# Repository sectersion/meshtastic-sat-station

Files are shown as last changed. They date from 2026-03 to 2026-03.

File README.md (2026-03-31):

# Meshtastic Satellite Weather Station
### A Hack Club Stasis Project

A self-contained, fully off-grid deployable kit that receives real-time weather data directly from GOES satellites and serves it on demand to any nearby Meshtastic mesh node — no internet, no cell service, no infrastructure required.

> Built for [Hack Club Stasis](https://stasis.hackclub.com)
NOTE TO REVIEWERS: The BOM present in my project was exported from google sheets and the links got deleted. The original google sheet is availible in the stasis project itself, and in the README.
---

## The Problem

Weather stations are common on urban LoRa meshes, but they rely on local sensors or internet-connected APIs. In a natural disaster, exactly when weather data matters most, power and internet go down first. A mesh node that can only tell you the temperature outside your window isn't very useful when a tornado is 40 miles away.

## The Solution

This kit receives structured meteorological data broadcasts directly from NOAA's GOES-East geostationary satellite using a software defined radio and a 3D printed helical antenna. It stores a rolling 7-day database of weather data and exposes a query bot on the Meshtastic mesh. Anyone within radio range can request a weather report with a simple command, no app, no internet, no setup on their end.

The entire system runs on solar power and a 3-cell 18650 battery pack, capable of operating for multiple days without sunlight.

---

## Query Interface

Any Meshtastic user within range can query the bot using plain text commands:

```
!wx 30.26 -97.74          → current conditions at coordinates
!wx 30.26 -97.74 3        → 3-day forecast
!fc AUS                   → forecast by airport/station ID
!warn TX                  → active NWS warnings for a state
!help                     → list available commands
```

Responses are formatted to stay under 200 characters, well within LoRa packet limits.

---

## System Architecture

```
GOES-East Satellite (1692.7 MHz EMWIN broadcast)
        |
3D Printed Helical Antenna (RHCP, tuned 1692.7 MHz)
        │
Nooelec SAWbird+ GOES LNA (powered via RTL-SDR bias tee)
        │
RTL-SDR Blog V3 (USB SDR dongle)
        │ USB
Raspberry Pi Zero 2W
 > goestools EMWIN decoder
 > SQLite database (7-day rolling store)
 > Meshtastic bot daemon (Python)
        │ USB serial
RAKWireless RAK4631 + RAK19007
        │ 915 MHz LoRa
Meshtastic mesh network
```

---

## Hardware

### Satellite Receive Chain
The GOES EMWIN signal at 1692.7 MHz broadcasts structured NWS text products: forecasts, warnings, METARs, and observations, in an unencrypted digital format receivable with commodity SDR hardware. The key components are:

- **3D Printed Helical Antenna** — custom designed in Fusion 360, printed on an Elegoo Centauri Carbon, wound with 18 AWG solid copper wire. Axial-mode helix provides natural right-hand circular polarization (RHCP) matching the satellite downlink. Aimed at GOES-East (~35° elevation, due south from Texas).
- **Nooelec SAWbird+ GOES LNA** — inline low-noise amplifier with SAW filter centered at 1688 MHz, providing >20 dB gain. Powered directly from the RTL-SDR V3 bias tee — no separate power required.
- **RTL-SDR Blog V3** — the industry standard hobbyist SDR dongle. Tunes up to ~1.7 GHz with excellent sensitivity.

### Mesh Radio
- **RAKWireless RAK4631** (nRF52840) + **RAK19007 base board** — low power Meshtastic node running stock Meshtastic firmware. Communicates with the Pi over USB serial using the Meshtastic Python library. The nRF52840 chipset draws significantly less power than ESP32-based alternatives, extending battery life.
- **Generic 915 MHz 5.8 dBi fiberglass antenna** — panel mounted to the exterior of the case with the included hardware mount. Omnidirectional, suitable for multi-day high-density mesh operation.

### Computing & Power
- **Raspberry Pi Zero 2W** — runs Raspberry Pi OS Lite, goestools, SQLite, and the bot daemon. Draws ~1.5W under load.
- **TP4056 charge controller** — manages charging of the 3-cell 18650 pack from the solar panels.
- **3x 18650 Li-Ion cells** (~10Ah) — provides ~48 hours of runtime without solar input.
- **2x ALLPOWERS 2.5W 5V solar panels** — wired in parallel, magnetically mounted to the case lid for deployment. Provides realistic 2-3W in partial sun, enough to sustain the system indefinitely in typical conditions.

### The Case
An IP67-rated 11×8×5" hard case serves as the foundation for the entire kit. Interior layout:

- **Left half** — 3D printed brain enclosure housing all electronics, with a magnetic front plate featuring an SSD1306 OLED display and 4 toggle switches
- **Right half** — 3D printed storage trays for the antenna, cables, and mast sections

External hardware includes SMA bulkheads, a cable gland for the solar panel, and the antenna mount — everything needed to go from closed case to fully deployed in under 2 minutes.

### Front Plate Controls
| Switch | Function |
|---|---|
| 1 | System power on/off |
| 2 | Mesh TX enable/disable |
| 3 | Display mode (system status / last query) |
| 4 | Force EMWIN data refresh |

The OLED display shows a split view: system status (satellite lock, battery, node count) on the top half, and the last mesh query and response on the bottom half.

---

## Software Stack

| Component | Technology |
|---|---|
| EMWIN decoder | goestools |
| Database | SQLite (7-day rolling window) |
| Bot daemon | Python, Meshtastic library |
| Display driver | Python, luma.oled |
| Auto-start | systemd services with watchdog |

---

## Deployment

1. Open case, prop lid open
2. Peel solar panels off lid interior stow frame, stick to exterior lid mount
3. Point helical antenna south (~175° azimuth, ~35° elevation) toward GOES-East
4. Flip power switch
5. Within ~60 seconds the Meshtastic node appears on the mesh and the bot is live

---

## BOM

Full bill of materials with pricing and links:
[Google Sheets BOM](https://docs.google.com/spreadsheets/d/1USlBK-dkPbo43bPHNxUITIbZjwFQk0WdP9H-Rfz2vz8/edit?usp=sharing)

**Approximate total: ~$294**

---

## Project Status

- [x] System architecture designed
- [x] BOM finalized
- [x] Front plate modeled in Fusion 360
- [ ] Parts on order
- [ ] EMWIN receive pipeline (goestools + SQLite)
- [ ] Meshtastic bot daemon
- [x] Brain enclosure modeled
- [ ] Helical antenna former modeled and wound
- [ ] Assembly
- [ ] Field test

---

## License

MIT

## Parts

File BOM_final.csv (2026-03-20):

Qty | Name | Purpose | PN | Cost | Link | Total: | 287
1 | RPI 02W | brain | 02W | 30 | link
1 | RTL-SDR Blog V3 R860 | SDR dongle | NA | 40 | link
1 | Nooelec SAWbird+ GOES | LNA | NA | 40 | link
1 | Tp4056 | Charge controller | TP4056 | 6 | link
1 | 18650 3 cell holder | cell holder | NA | 6 | link
1 | 4 pack 3.7v 18650 cell (1 spare) | battery | 18650 | 16 | link
1 | 32GB microSD card | for pi | NA | 9 | link
1 | knockoff pelican case - 11 x 8 x 5 in | enclosure | NA | 26 | link
1 | SMA bulkhead connectors 2 pack | front panel and box | NA | 7 | link
1 | nRF52 meshtastic node | MTS | RAK4631 | 18 | link
1 | meshtastic base board | MTS | RAK19007 | 10 | link
1 | cable gland kit | cheapest one I could find | NA | 8 | link
1 | 3x10mm magnets | cheaper than amazon | NA | 5 | aliexpess
1 | RG316 sma to sma cables 3 pack | <-- | NA | 7 | link
1 | cheap amazon antenna | main 915mhz whip | NA | 18 | link
1 | dust covers sma | <-- | NA | 2 | link
1 | ALLPOWERS solar panel 2x2.5w | auxillary power | NA | 18 | link
1 | 6pcs usbc power pigtail | to connect to tp4056 | NA | 7 | link
1 | 22awg wire | power and other stuff | NA | 8 | link
1 | OLED 0.96in | HUD | NA | 6 | link

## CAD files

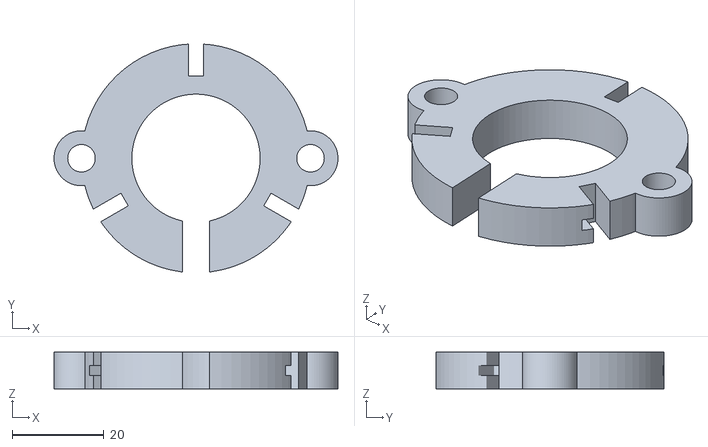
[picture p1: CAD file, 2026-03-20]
models/l-band-helix-bottom-disc-spacer-full-slot.stl
62.0 x 49.7 x 8.00

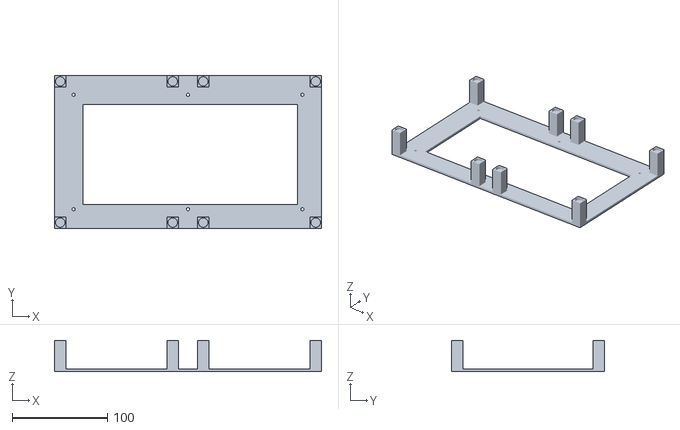
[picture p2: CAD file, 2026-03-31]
models/solar_deploy_mount.stl
280.0 x 160.0 x 33.0

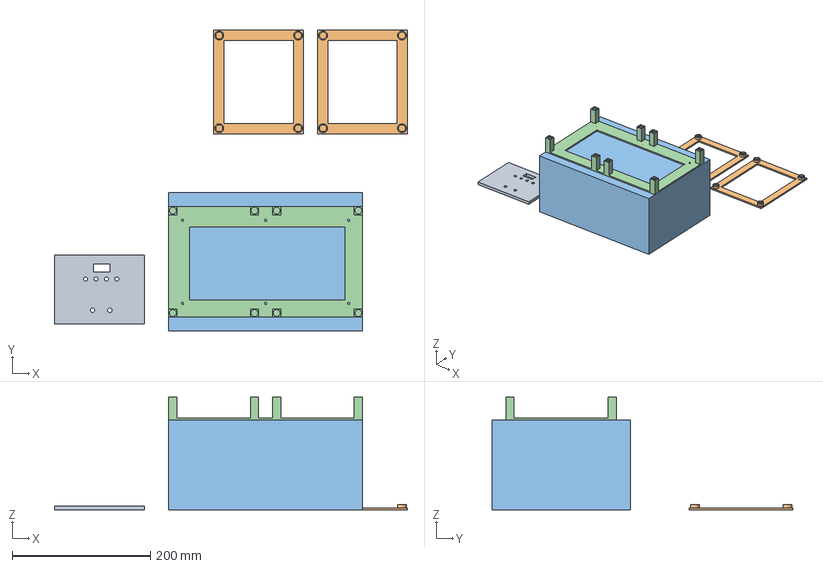
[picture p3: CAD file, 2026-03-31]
panelmount.step
510.0 x 435.0 x 163.0 mm

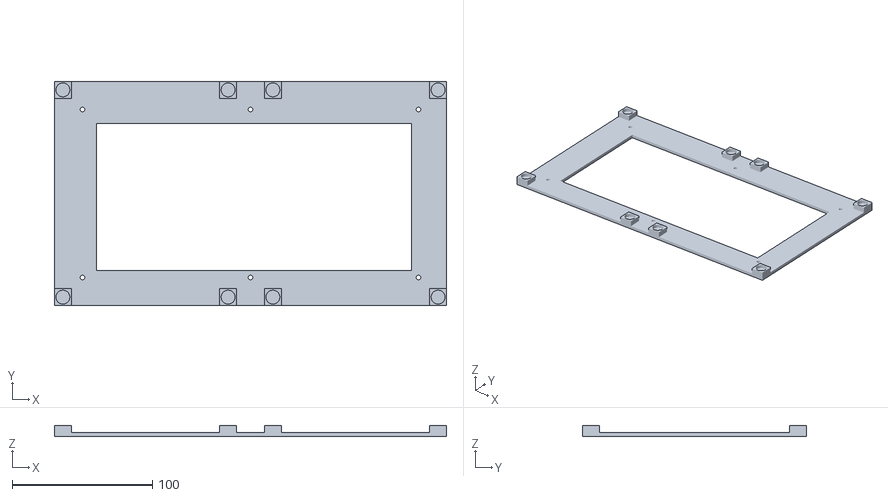
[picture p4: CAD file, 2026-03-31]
models/solar_stow_mount.stl
280.0 x 160.0 x 8.00

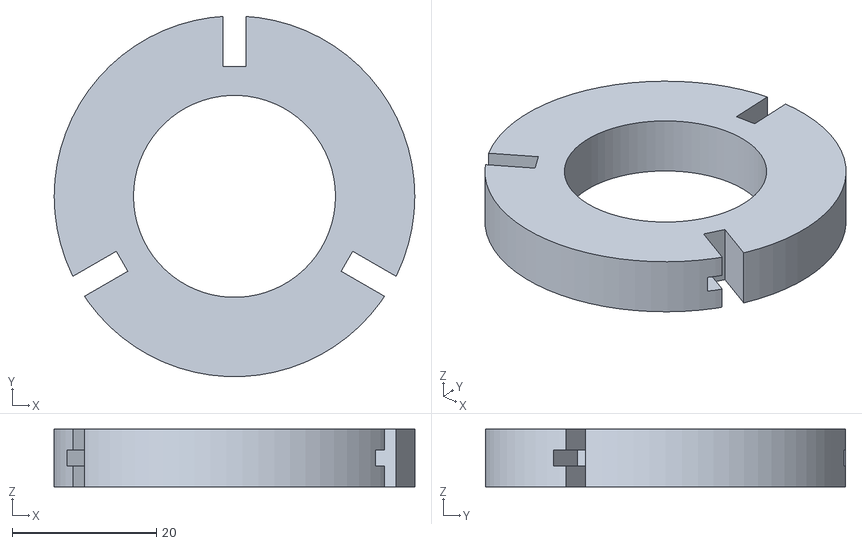
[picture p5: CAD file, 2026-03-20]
models/l-band-helix-upper-disc-spacer.stl
50.0 x 49.9 x 8.00

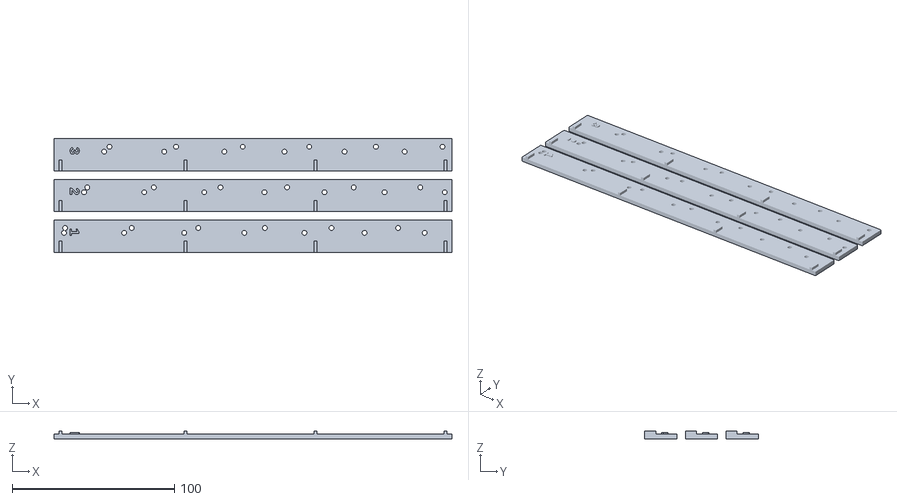
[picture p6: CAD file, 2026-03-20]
models/l-band-helix-vertical-struts.stl
245.0 x 70.0 x 4.90

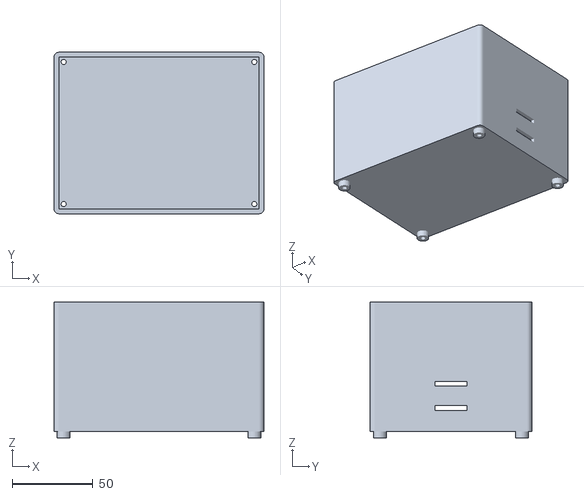
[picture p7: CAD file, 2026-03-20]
models/brain_box.stl
130.0 x 100.0 x 84.0

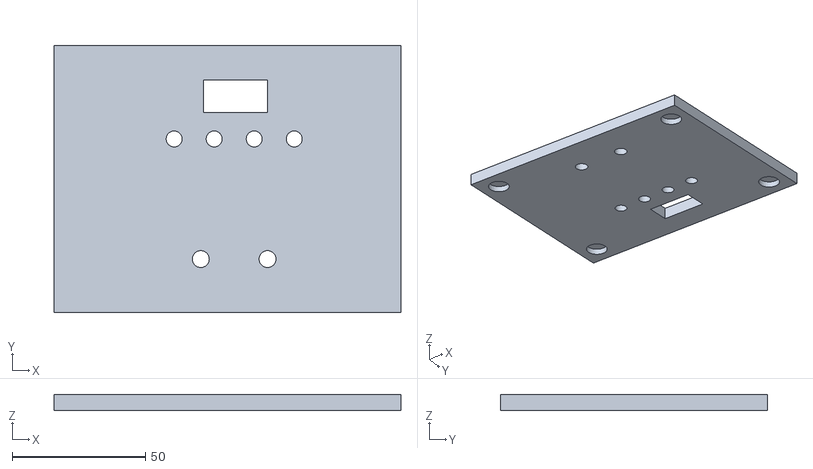
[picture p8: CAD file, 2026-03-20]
models/front_magnet_plate.stl
130.0 x 100.0 x 6.00

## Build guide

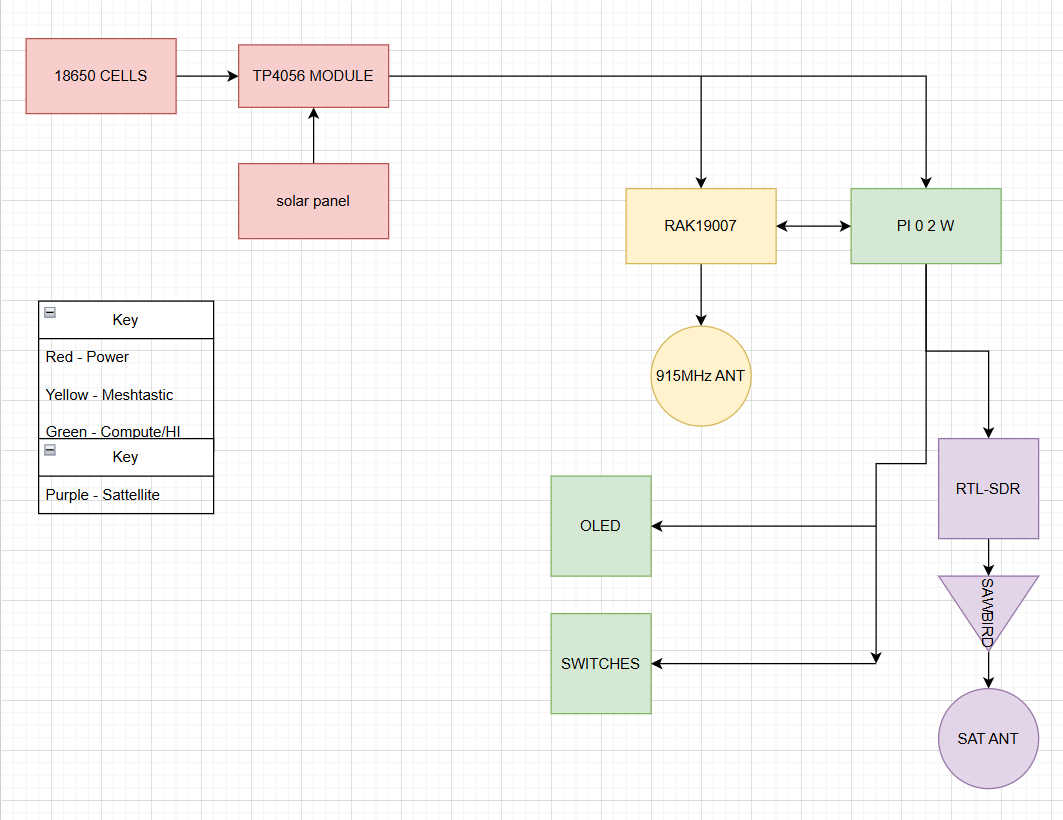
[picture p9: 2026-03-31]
wiringdiagram.png

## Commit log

2026-03-20 Add reviewer note regarding BOM links
    Added a note to reviewers about the BOM links in the project.
2026-03-21 wiring diagram
